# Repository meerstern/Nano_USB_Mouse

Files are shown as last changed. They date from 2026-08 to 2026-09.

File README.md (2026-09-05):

# Overview
  * This is a compact mouse equipped with 5 directional pad, size 14mm x 25mm.  
  * It features up, down, left, right, center buttons, and left/right click buttons.
  * The center button functions the same as the left mouse button.  
  * If you continue to tilt the knob, the speed changes in two stages.  
  * Suitable for small PCs and SBCs(Single Board Computers, like Raspberry Pi).   
  * It operates using standard drivers, without the need for a dedicated driver.   
  * You can change the mouse orientation according to the direction of the USB port.  

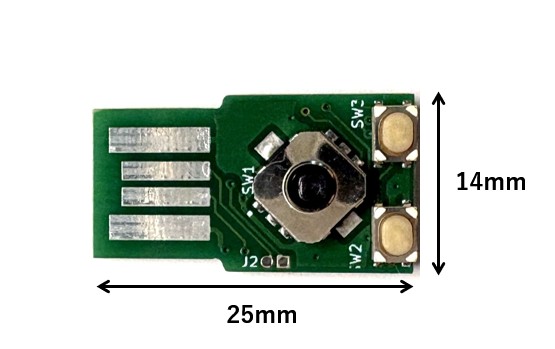
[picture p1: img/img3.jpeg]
  

# Direction Setting
  * To configure the mouse orientation, insert the USB connector while holding the knob tilted in the desired "up" direction.   
  * The settings will be applied immediately.
  * If the settings are not applied, please perform the procedure again.  
  * The configuration data is automatically saved to flash memory.   
  * The orientation does not need to be set again for subsequent uses.  
  * The configuration data supports up to approximately 10,000 rewrite cycles.  
  * If you do not wish to change the orientation, connect this device to the USB port without pressing any buttons.  
 
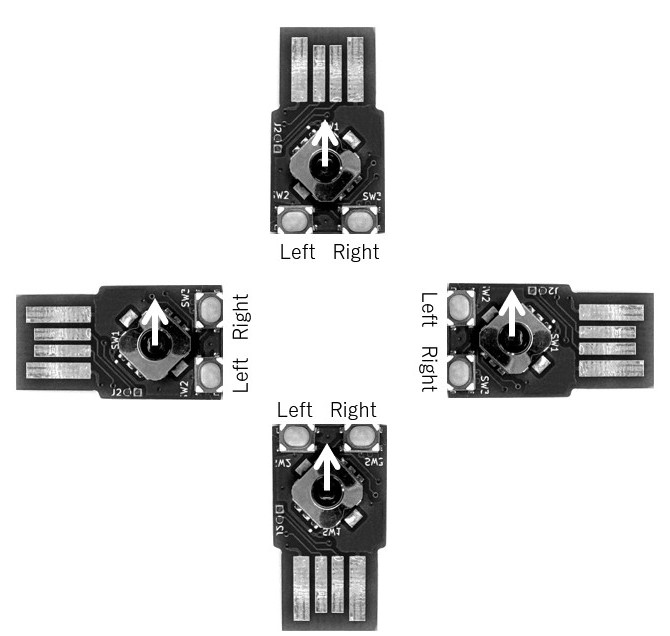
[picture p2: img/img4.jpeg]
  

# Target user
  * It is ideal for users who primarily use a keyboard and don't need a mouse, but still want to use one occasionally.  
  * It is ideal as a stopgap measure until the drivers for the mouse pad or touch panel are installed.
  * It is convenient to use in combination with a [Nano USB Scroller][1].  

# Note
  * Due to the use of up, down, left, and right buttons, diagonal movement is not possible.  
  * Please take care not to short-circuit or damage components on the back of the board.    
  * Please operate the knob gently. Operating it with excessive force may cause damage.  
  * PCB color, LED color, and other specifications are subject to change without notice.
    
## Appearance and examples
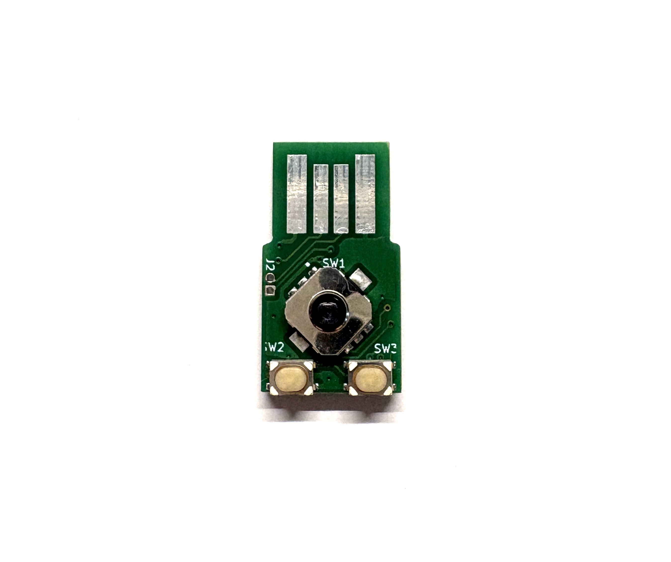
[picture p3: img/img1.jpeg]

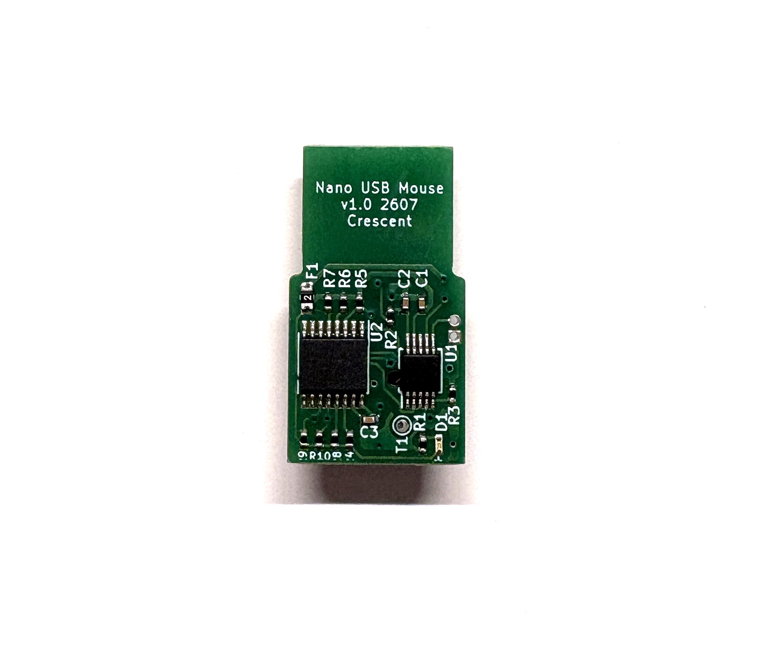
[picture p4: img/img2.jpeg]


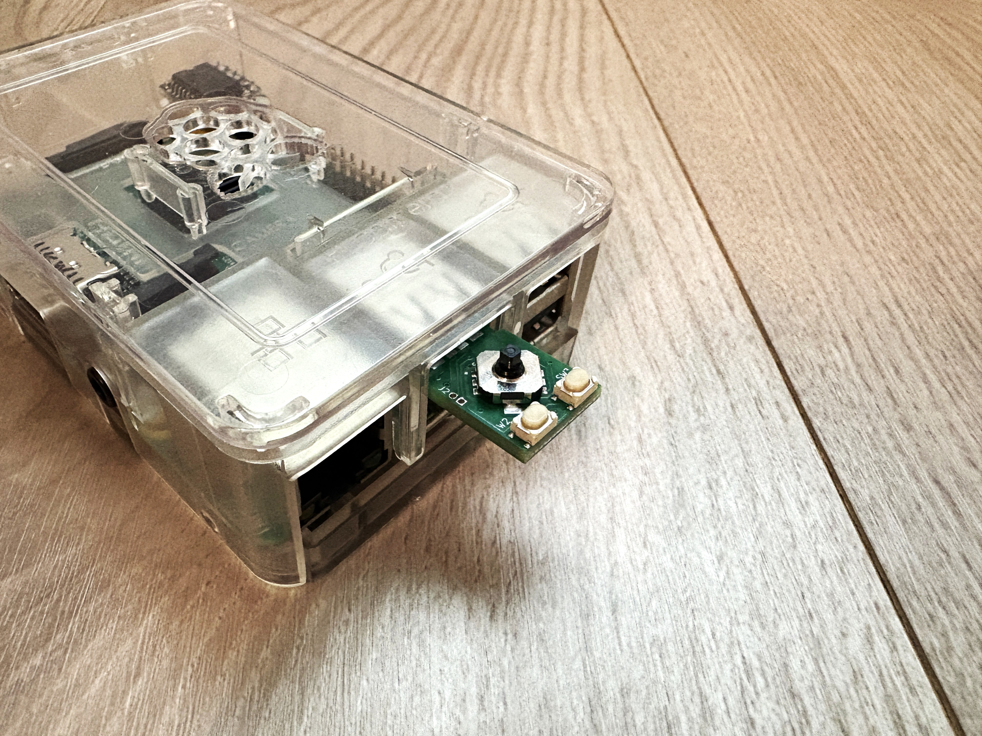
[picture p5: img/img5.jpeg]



Combination use with the USB Nano Scroller 

[1]: https://github.com/meerstern/Nano_USB_Scroller/

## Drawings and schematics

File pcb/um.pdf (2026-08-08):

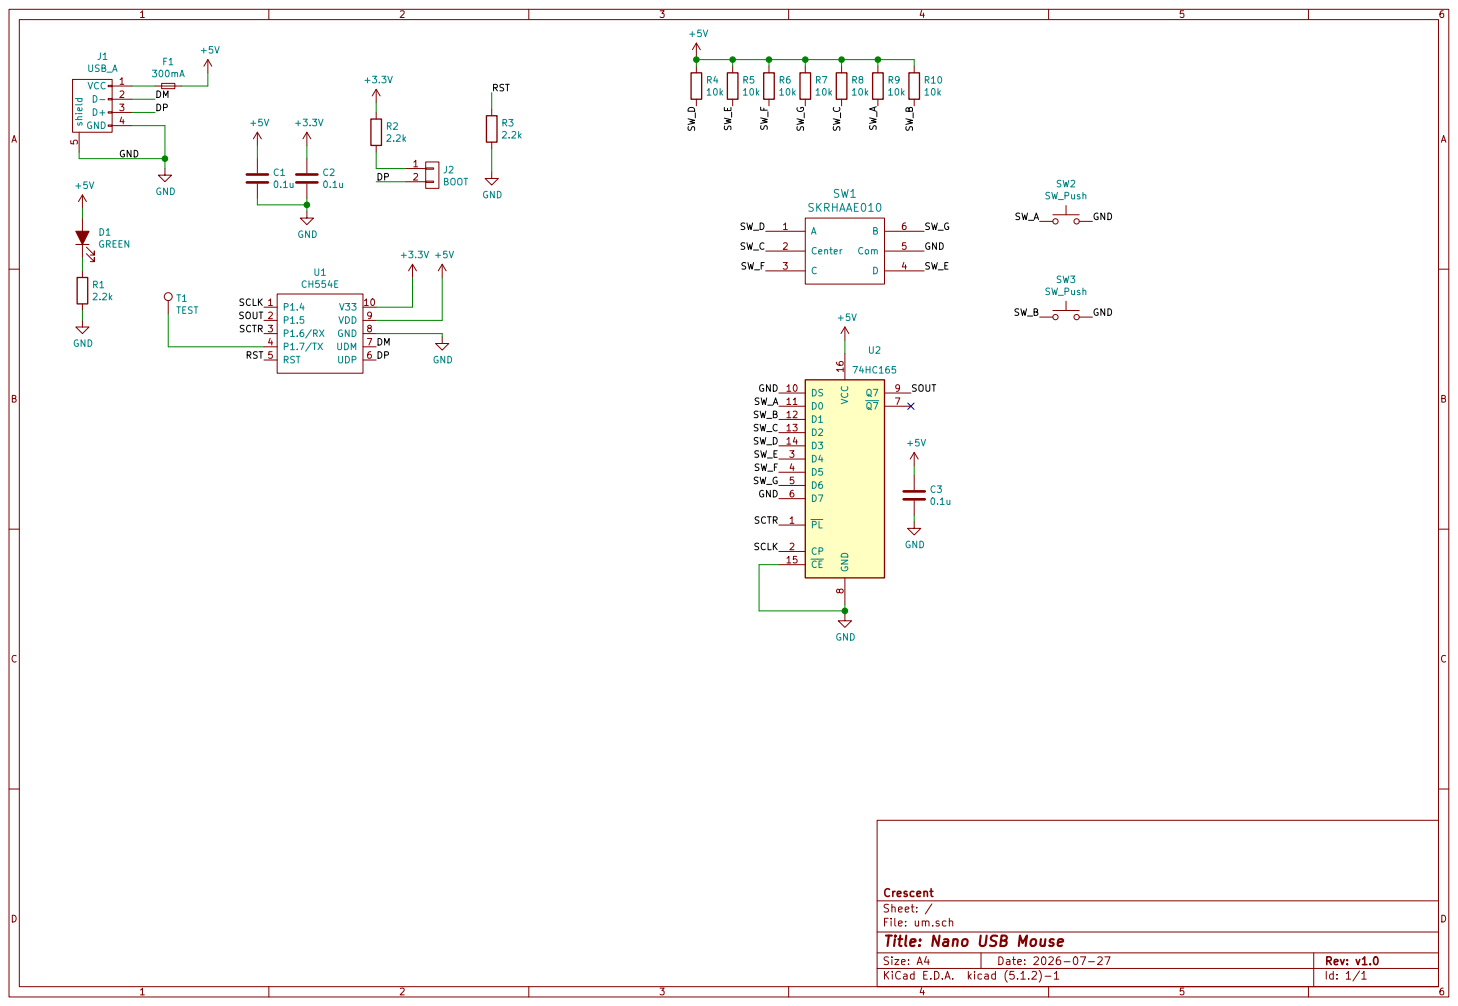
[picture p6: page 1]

File: um.sch Sheet: / Crescent

Id: 1/1 Title: Nano USB Mouse

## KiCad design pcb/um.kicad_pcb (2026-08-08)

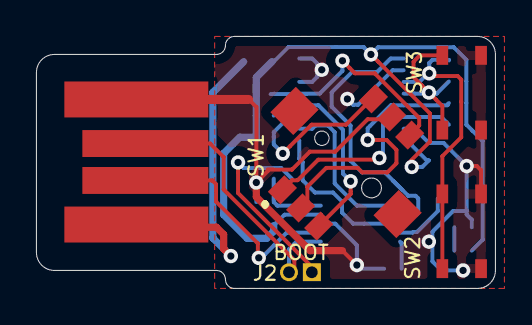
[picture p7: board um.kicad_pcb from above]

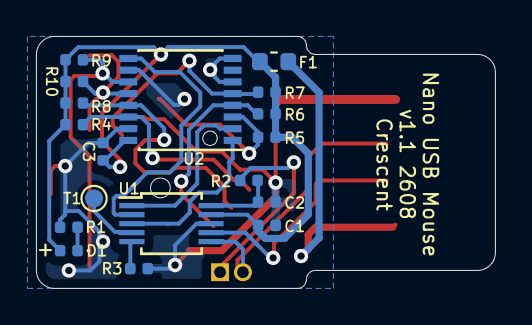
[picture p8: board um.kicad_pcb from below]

Board: 2 copper layers, 25.5 x 14.0 mm, 23 parts (18 on the bottom side), 20 nets.

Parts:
C1, C2, C3: 0.1u; C_0402_1005Metric
D1: GREEN; LED_0402_1005Metric
F1: 300mA; Fuse_0603_1608Metric
J1: USB_A; usbpcb
J2: BOOT; PinHeader_2x01_P1.27mm_Vertical
R1, R2, R3: 2.2k; R_0402_1005Metric
R4, R5, R6, R7, R8, R9, R10: 10k; R_0402_1005Metric
SW1: SKRHAAE010
SW2, SW3: SW_Push; SKRPACE010
T1: TEST; TestPoint_Pad_D1.0mm
U1: CH554E; MSOP-10_3x3mm_P0.5mm
U2: 74HC165; SSOP-16_4.4x5.2mm_P0.65mm

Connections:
+3V3: C2.1, R2.1, U1.10
+5V: C1.1, C3.1, D1.2, F1.2, R4.1, R5.1, R6.1, R7.1, R8.1, R9.1, R10.1, U1.9, U2.16
/DM: J1.2, U1.7
/DP: J1.3, J2.2, U1.6
/RST: R3.1, U1.5
/SCLK: U1.1, U2.2
/SCTR: U1.3, U2.1
/SOUT: U1.2, U2.9
/SW_A: R9.2, SW2.1, U2.11
/SW_B: R10.2, SW3.1, U2.12
/SW_C: R8.2, SW1.2, U2.13
/SW_D: R4.2, SW1.1, U2.14
/SW_E: R5.2, SW1.4, U2.3
/SW_F: R6.2, SW1.3, U2.4
/SW_G: R7.2, SW1.6, U2.5
GND: C1.2, C2.2, C3.2, J1.4, R1.2, R3.2, SW1.5, SW2.2, SW3.2, U1.8, U2.6, U2.8, U2.10, U2.15
unnamed: D1.1, R1.1
unnamed: F1.1, J1.1
unnamed: J2.1, R2.2
unnamed: T1.1, U1.4

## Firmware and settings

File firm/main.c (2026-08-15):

#include <stdio.h>
#include <stdint.h>
#include <stdbool.h>
#include "debug.h"

#include "ch554.h"
#include "mouse.h"
#include "flash.h"


#define SCLK_PIN	4	//OUT
#define SOUT_PIN	5	//IN
#define SCTR_PIN	6	//OUT

#define delayUs	mDelayuS

#define INPUT_MASK		0x7F
#define MOVE_MASK		0x78
#define BUTTON_MASK		0x03

#define ADDRESS_DIRECTION	0		//Flash Address for Direction Memory
#define MOUSE_MOVE_DELTA	2		//Joystick Normal Speed
#define MOUSE_MOVE_SCALE	4		//Joystick Speed Up Scale
#define MOUSE_COUNT_MAX		20		//Joystick Speed Up Count

enum{
	BOTTOM_SIDE_USB_MODE,	
	UP_SIDE_USB_MODE,	
	LEFT_SIDE_USB_MODE,
	RIGHT_SIDE_USB_MODE,
	USB_MODE_MAX
};

enum{
	SPEED_LOW,
	SPEED_MID,
	SPEED_HIGH	
};

enum{
		BTN_A,	//0
		BTN_B,	//1
		JOY_C,	//2
		JOY_D,	//3
		JOY_E,	//4
		JOY_F,	//5
		JOY_G	//6
};

SBIT(SCLK, 0x90, SCLK_PIN);
SBIT(SOUT, 0x90, SOUT_PIN);
SBIT(SCTR, 0x90, SCTR_PIN);

bool BtnLeft 	= false;
bool BtnRight	= false;
bool JoyUp 		= false;
bool JoyDown 	= false;
bool JoyLeft 	= false;
bool JoyRight 	= false;


void initGPIO(void)
{	
	//Input Pullup
	P1_MOD_OC |= SOUT_PIN;
    P1_DIR_PU |= SOUT_PIN;	
	
	P1_MOD_OC = P1_MOD_OC & ~(1<<SCLK_PIN);
    P1_DIR_PU = P1_DIR_PU |	(1<<SCLK_PIN);
	
	P1_MOD_OC = P1_MOD_OC & ~(1<<SCTR_PIN);
    P1_DIR_PU = P1_DIR_PU |	(1<<SCTR_PIN);
	
	SCTR = 1;
	SCLK = 0;
}

unsigned short shiftIn()
{	

  unsigned short  data;

  SCTR = 0;
  delayUs(5);
  SCTR = 1;
  delayUs(5);
  data = SOUT&0x01;
  
  for (unsigned short  i=1; i<8; i++){
    SCLK = 1;
	delayUs(5);
    data = data << 1 | (SOUT&0x01);
    SCLK = 0;
	delayUs(5);
  }

  return data;
}

void convertMode(unsigned char mode, unsigned char data, 
	bool *left_btn, bool *right_btn, 
	bool *up, bool *down, bool *left, bool *right)
{
	unsigned char dat = ~data;//Logic Inverted
	 	
	if(mode==BOTTOM_SIDE_USB_MODE)
	{
		*left_btn 	= (dat>>BTN_B)&0x01|(dat>>JOY_C)&0x01;
		*right_btn 	= (dat>>BTN_A)&0x01;								
	}
	else
	{
		*left_btn  	= (dat>>BTN_A)&0x01|(dat>>JOY_C)&0x01;
		*right_btn	= (dat>>BTN_B)&0x01;
	}
	
	if(mode==LEFT_SIDE_USB_MODE)
	{
		*up 		= (dat>>JOY_G)&0x01;
		*down 		= (dat>>JOY_D)&0x01;
		*left 		= (dat>>JOY_F)&0x01;
		*right 		= (dat>>JOY_E)&0x01;
	}
	else if(mode==RIGHT_SIDE_USB_MODE)
	{
		*up 		= (dat>>JOY_D)&0x01;
		*down 		= (dat>>JOY_G)&0x01;
		*left 		= (dat>>JOY_E)&0x01;
		*right 		= (dat>>JOY_F)&0x01;
	}
	else if(mode==BOTTOM_SIDE_USB_MODE)
	{
		*up 		= (dat>>JOY_F)&0x01;
		*down 		= (dat>>JOY_E)&0x01;	
		*left 		= (dat>>JOY_D)&0x01;
		*right 		= (dat>>JOY_G)&0x01;
	}
	else //mode==UP_SIDE_USB_MODE
	{
		*up 		= (dat>>JOY_E)&0x01;
		*down 		= (dat>>JOY_F)&0x01;
		*left 		= (dat>>JOY_G)&0x01;
		*right 		= (dat>>JOY_D)&0x01;
	}	
}


void main()
{
	CfgFsys();
	mInitSTDIO();
	initGPIO();
	
	int8_t moveX = 0;
	int8_t moveY = 0;
	unsigned char move = 0;
	//unsigned char moveOld = 0;
	unsigned char btn = 0;
	unsigned char btnOld = 0;
	unsigned char direction = UP_SIDE_USB_MODE;
	unsigned char joyCount = 0;
	
	unsigned short dat = 0;
	dat = shiftIn();
	mDelaymS(1);
	dat = shiftIn();
		
	convertMode(UP_SIDE_USB_MODE, dat, 
				&BtnLeft, &BtnRight, 
				&JoyUp, &JoyDown, &JoyLeft, &JoyRight);
	
	if(JoyUp||JoyDown||JoyLeft||JoyRight)
	{
		if(JoyDown)
		{			
			direction = RIGHT_SIDE_USB_MODE;
		}
		else if(JoyLeft)
		{
			direction = BOTTOM_SIDE_USB_MODE;			
		}
		else if(JoyRight)
		{			
			direction = UP_SIDE_USB_MODE;
		}
		else	//JoyUp
		{
			direction = LEFT_SIDE_USB_MODE;
		}
		writeDataFlash(ADDRESS_DIRECTION, &direction, 1);
	}
	else
	{
		readDataFlash(ADDRESS_DIRECTION, &direction, 1);
	}
	mDelaymS(5);

	mouse_init();

	while(1)
	{
		dat = shiftIn();
		//move = dat & MOVE_MASK;
		//btn = dat &BUTTON_MASK;
		convertMode(direction, dat, 
				&BtnLeft, &BtnRight, 
				&JoyUp, &JoyDown, &JoyLeft, &JoyRight);
		
		
		if(JoyUp||JoyDown||JoyLeft||JoyRight)
		{
			if(JoyUp)
				moveX = MOUSE_MOVE_DELTA;
			else if(JoyDown)
				moveX = -MOUSE_MOVE_DELTA;
			else
				moveX = 0;
			
			if(JoyLeft)
				moveY = MOUSE_MOVE_DELTA;
			else if(JoyRight)
				moveY = -MOUSE_MOVE_DELTA;
			else
				moveY = 0;
			
			if(joyCount < MOUSE_COUNT_MAX)
				joyCount++;
			
			//Speed Up
			if(joyCount >= MOUSE_COUNT_MAX)
			{
				moveX = moveX*MOUSE_MOVE_SCALE;
				moveY = moveY*MOUSE_MOVE_SCALE;
			}
			
		}
		else
		{
			joyCount = 0;
		}
		

		btn = (uint8_t)BtnLeft*MOUSE_LEFT_BUTTON + (uint8_t)BtnRight*MOUSE_RIGHT_BUTTON;

		if(JoyUp || JoyDown || JoyLeft || JoyRight || BtnLeft || BtnRight || btnOld != btn)
		{
			if(JoyUp + JoyDown + JoyLeft + JoyRight == 0)
			{
				moveX = 0;
				moveY = 0;				
			}
			
			hidValueHandle(btn, moveX, moveY, 0);

			btnOld = btn;
			//moveOld = move;
			mDelaymS(5);
		}
		
	}
}
